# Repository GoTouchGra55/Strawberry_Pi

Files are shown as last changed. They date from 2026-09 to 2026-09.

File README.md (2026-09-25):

# 🍓 Strawberry Pi

A Raspberry Pi-4 form factor STM32 development board designed as a compact computing platform.

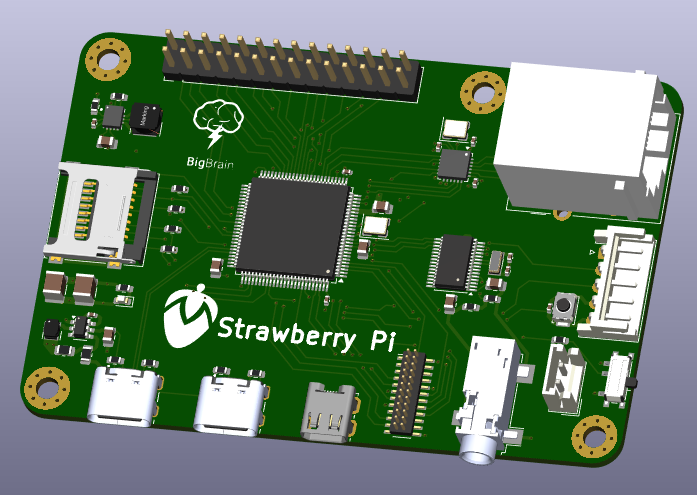
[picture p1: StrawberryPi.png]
Strawberry Pi


## Overview

Strawberry Pi is a custom 4-layer STM32-based development platform built around the **STM32H743** Cortex-M7 micro-controller.

The goal was to take the general concept of a small single-board computer and recreate it around a powerful micro-controller, integrating many useful interfaces and peripherals as possible into a compact Raspberry Pi 4 form factor.

The board is intended as a development and experimentation platform for hardware projects.

**SEE [SCHEMATICS](Strawberry_Pi-4.pdf)**

## Routing

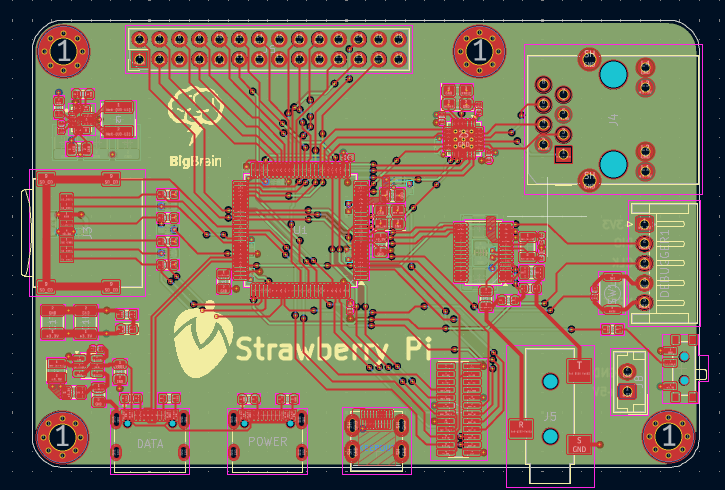
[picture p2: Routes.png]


## Features

### Core

- **STM32H743** Cortex-M7 MCU
- Up to **480 MHz** CPU clock
- MicroSD storage
- SWD debugging

### Connectivity

- **Ethernet**
- USB-C
- I2C
- SPI
- UART

### Multimedia

- Camera interface via **DCMI**
- Digital audio interface via **SAI**
- PCM1862 audio ADC
- 3.5 mm stereo audio input

### Power

The board provides dedicated:

- **5 V rail**
- **3.3 V rail**

## Rough BOM
| # | Item | Cost | Supplier |
|---|---|---:|---|
| 1 | PCB | $154.23 | JLCPCB |
| 2 | SMD Resistors | $8.35 | Daraz Nepal |
| 3 | SMD Capacitors | $7.98 | Daraz Nepal |
| | **Total** | **$170.56** | |

## Authors 👥

### Shaurya (Electronics)

Contact: [Email](shauryatamang.dev@gmail.com)

### Krish (CAD)

View: [Github](https://github.com/unknowngamer69/)

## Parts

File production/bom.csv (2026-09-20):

Designator | Footprint | Quantity | Value | LCSC Part #
 |  | 1
C1, C12, C16, C2, C23, C24, C26, C27, C28, C29, C3, C35, C4, C40, C5, C6, C8 | 0402 | 17 | 100nF
C10, C11, C30, C31 | 0402 | 4 | 18pF
C13, C14, C15 | 0805 | 3 | 2.2uF
C17, C18, C20, C21, C22, C33, C34 | 1210 | 7 | 22uF
C19, C25, C32, C36, C37 | 0805 | 5 | 10uF
C38, C39 | 0402 | 2 | 15pF
C7 | 0805 | 1 | 4.7uF
C9 | 0805 | 1 | 1uF
D1 | 0603 | 1 | GREEN
DEBUGGER1 | JST_EH_S5B-EH_1x05_P2.50mm_Horizontal | 1 | Conn_01x05_Pin
FB1 | 0603 | 1 | FerriteBead
J1 | SHOUHAN_TYPE-C_16PIN_2MD__073_ | 1 | POWER
J2 | SHOUHAN_TYPE-C_16PIN_2MD__073_ | 1 | DATA
J3 | microSD_HC_Wuerth | 1 | Micro_SD_Card_Det1
J4 | RJ45_Bel_SI-60062-F | 1 | RJ45_Bel_SI-60062-F
J5 | Jack_3.5mm_CUI_SJ-3523-SMT_Horizontal | 1 | AudioJack3
J6 | PinHeader_2x14_P2.54mm_Vertical | 1 | Conn_02x14_Counter_Clockwise
J7 | PinHeader_2x12_P1.00mm_Vertical_SMD | 1 | Conn_02x12_Odd_Even
J8 | JST_EH_B2B-EH-A_1x02_P2.50mm_Vertical | 1 | Conn_01x02_Pin
J9 | HDMI_Micro-D_Molex_46765-1xxx | 1 | HDMI_A
L1 | L_Wurth_WE-LQSH-2512 | 1 | 5.6uH
L2 | L_Wurth_WE-LQSH-4020 | 1 | 1.5uH
R1, R10, R12, R13, R14, R15, R16, R17, R9 | 0603 | 9 | 10K
R11 | 0603 | 1 | 33K
R18, R19 | 0603 | 2 | 2.2K
R2, R3, R7, R8 | 0603 | 4 | 5.1K
R4 | 0805 | 1 | 100K
R5 | 0805 | 1 | 22.1K
R6 | 0603 | 1 | 120R
SW1 | SW_Push_SPST_NO_Alps_SKRK | 1 | RESET
SW2 | SW_SPDT_PCM12 | 1 | BOOT
U1 | LQFP-100_14x14mm_P0.5mm | 1 | STM32H743VITx
U2 | SOT-23-6 | 1 | LMR51430
U3 | VREG_TPS63070RNMR | 1 | TPS63070RNMR
U4 | VQFN-24-1EP_4x4mm_P0.5mm_EP2.5x2.5mm_ThermalVias | 1 | LAN8742A
U5 | TSSOP-30_4.4x7.8mm_P0.5mm | 1 | PCM1862DBT
Y1, Y2 | Crystal_SMD_3225-4Pin_3.2x2.5mm | 2 | 25MHz
Y3 | Crystal_SMD_3215-2Pin_3.2x1.5mm | 1 | 8MHz

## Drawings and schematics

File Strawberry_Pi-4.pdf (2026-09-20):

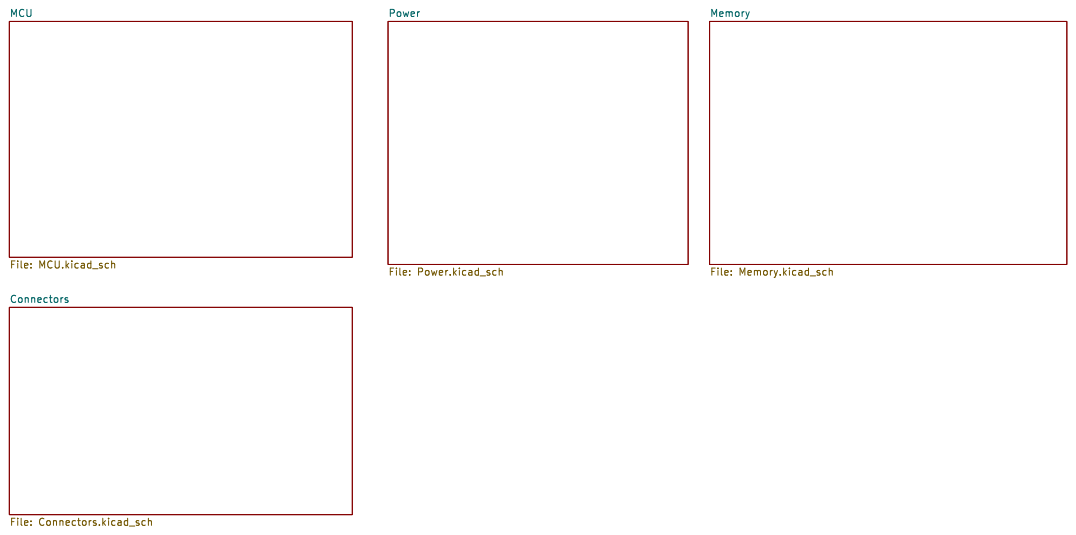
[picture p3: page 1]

Id: 1/5 Title: File: Strawberry_Pi-4.kicad_sch Sheet: /

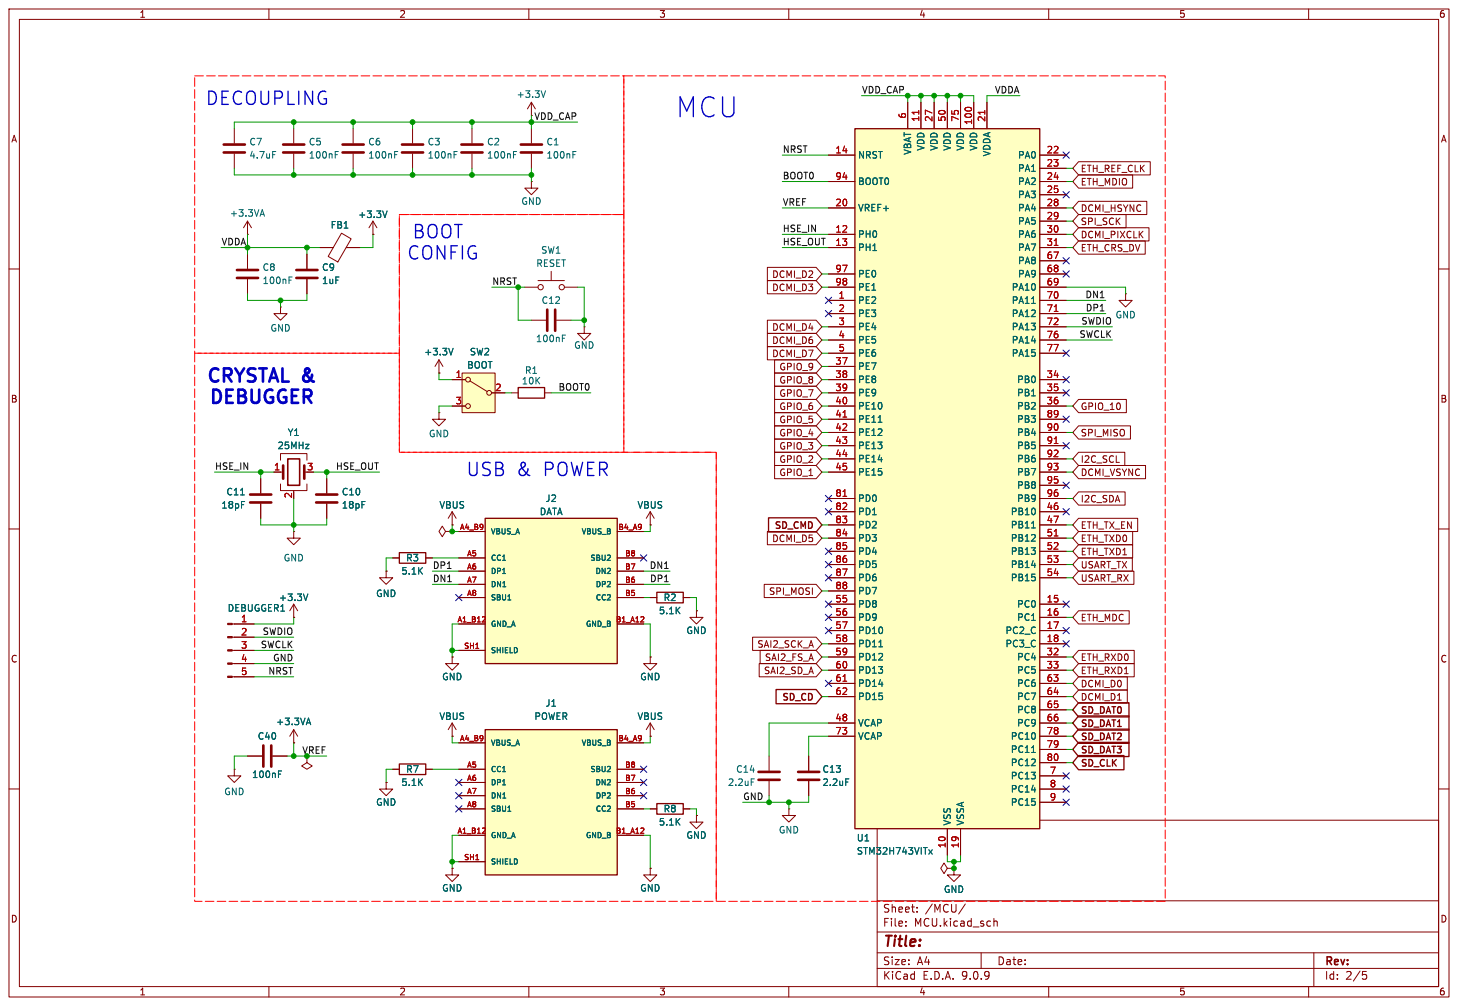
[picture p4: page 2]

Id: 2/5 Title: File: MCU.kicad_sch Sheet: /MCU/

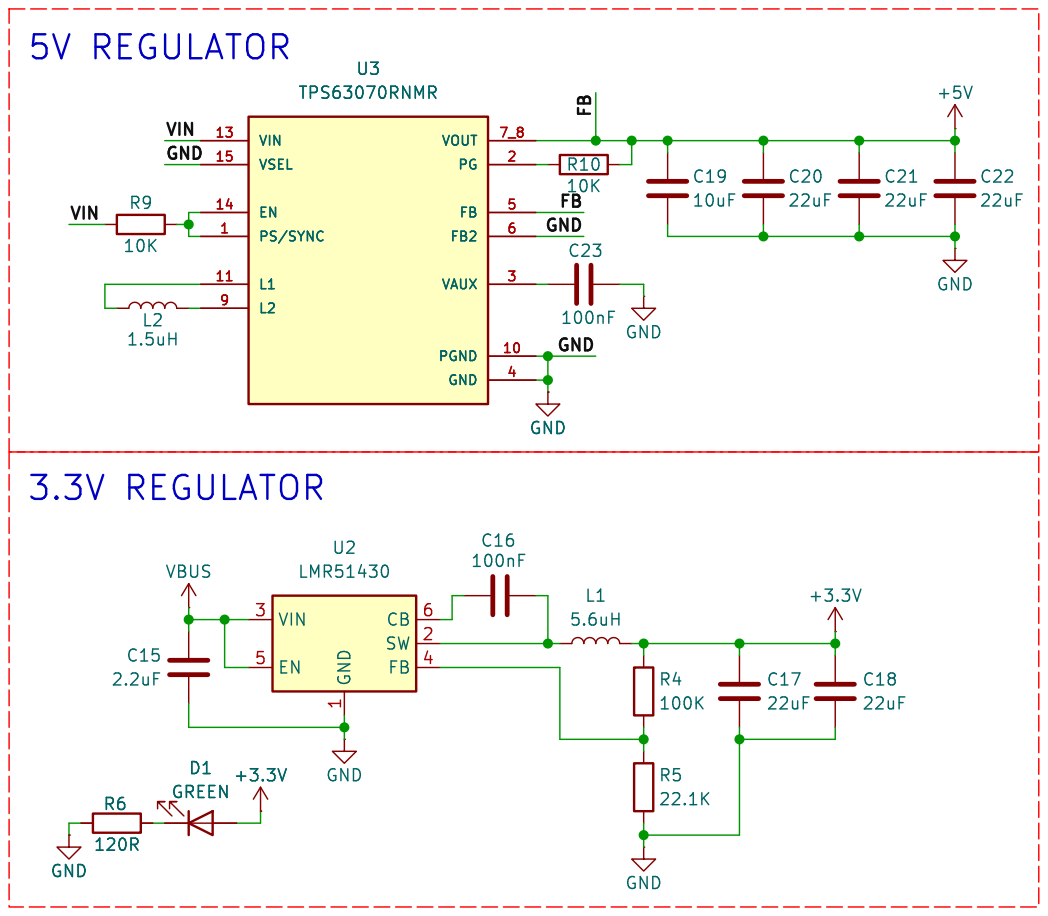
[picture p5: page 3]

Id: 3/5 Title: File: Power.kicad_sch Sheet: /Power/

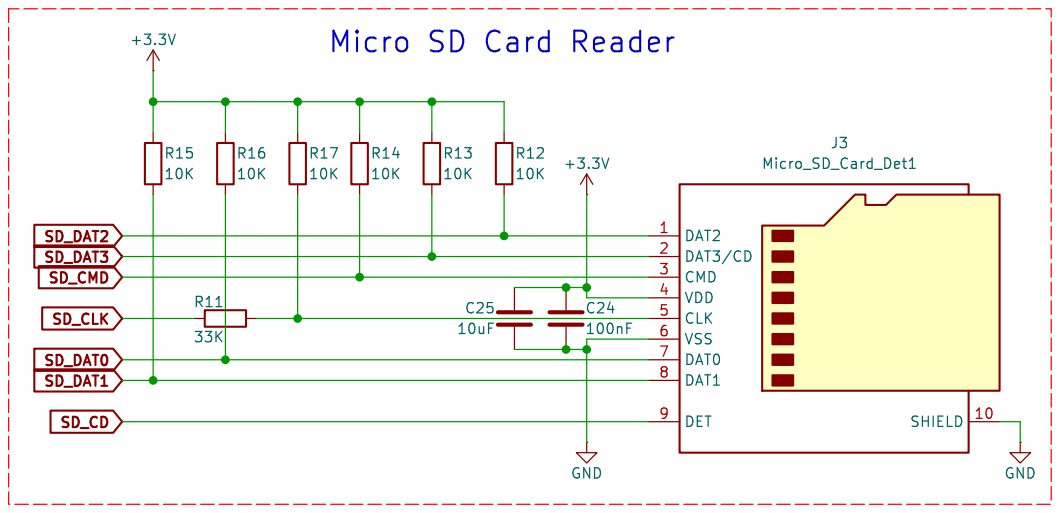
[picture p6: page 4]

Id: 4/5 Title: File: Memory.kicad_sch Sheet: /Memory/

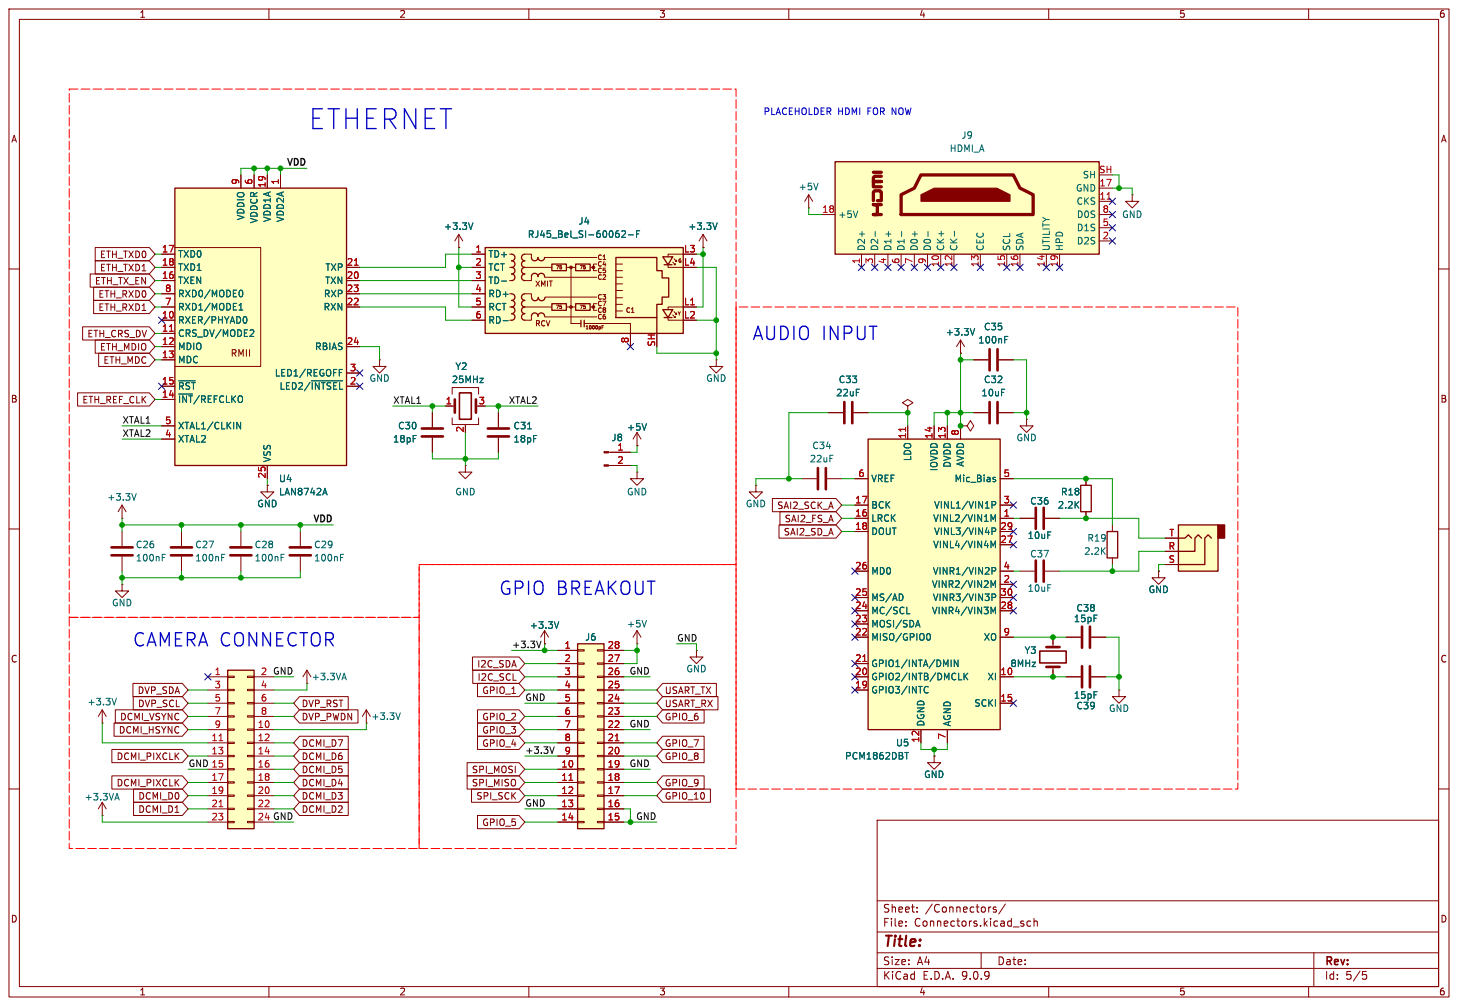
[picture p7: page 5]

PLACEHOLDER HDMI FOR NOW CAMERA CONNECTOR

7 D0- 9 CK+ 10 CK- 12 CEC 13 SCL 15 SDA 16 UTILITY 14 HPD 19 D2S 2 D1S 5 +5V 18 D0S 8 CKS 11 GND 17 SH SH
+3.3VGND

1 TXP 21 TXN 20 RXP 23 RXN 22 RBIAS 24

7 IOVDD 14 DGND 12 LDO 11 VREF 6 BCK 17

Id: 5/5 Title: File: Connectors.kicad_sch Sheet: /Connectors/

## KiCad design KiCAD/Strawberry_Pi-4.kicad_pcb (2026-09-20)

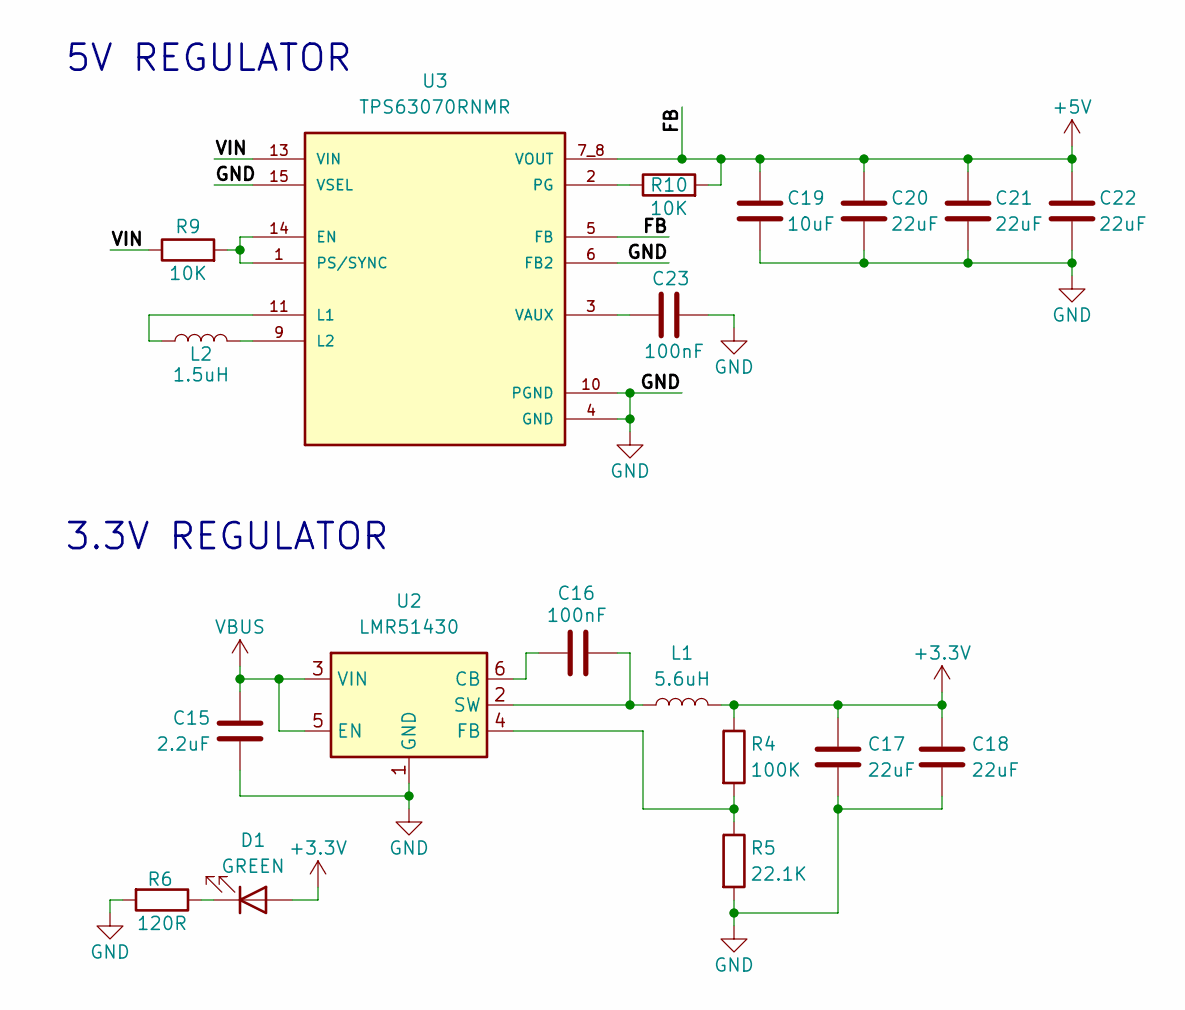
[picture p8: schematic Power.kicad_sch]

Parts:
C15: 2.2uF; C_0805_2012Metric
C16, C23: 100nF; C_0402_1005Metric
C17, C18, C20, C21, C22: 22uF; C_1210_3225Metric
C19: 10uF; C_0805_2012Metric
D1: GREEN; LED_0603_1608Metric
L1: 5.6uH; L_Wurth_WE-LQSH-2512
L2: 1.5uH; L_Wurth_WE-LQSH-4020
R4: 100K; R_0805_2012Metric
R5: 22.1K; R_0805_2012Metric
R6: 120R; R_0603_1608Metric
R9, R10: 10K; R_0603_1608Metric
U2: LMR51430; SOT-23-6
U3: TPS63070RNMR; VREG_TPS63070RNMR; PARTREV B

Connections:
+3.3V: C17.1, C18.1, D1.2 (A), L1.2, R4.1; also elsewhere on the board
+5V: C19.1, C20.1, C21.1, C22.1, R10.2, U3.5 (FB), U3.7_8 (VOUT); also elsewhere on the board
/Power/VIN: R9.1, U3.13 (VIN)
GND: C15.2, C17.2, C18.2, C19.2, C20.2, C21.2, C22.2, C23.2, R5.2, R6.2, U2.1 (GND), U3.4 (GND), U3.6 (FB2), U3.10 (PGND), U3.15 (VSEL); also elsewhere on the board
unnamed: D1.1 (K), R6.1
unnamed: C16.2, U2.6 (CB)
unnamed: R4.2, R5.1, U2.4 (FB)
unnamed: C16.1, L1.1, U2.2 (SW)
unnamed: R9.2, U3.1 (PS/SYNC), U3.14 (EN)
unnamed: L2.1, U3.11 (L1)
unnamed: L2.2, U3.9 (L2)
unnamed: R10.1, U3.2 (PG)
unnamed: C23.1, U3.3 (VAUX)
VBUS: C15.1, U2.3 (VIN), U2.5 (EN); also elsewhere on the board

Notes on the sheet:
5V REGULATOR
3.3V REGULATOR

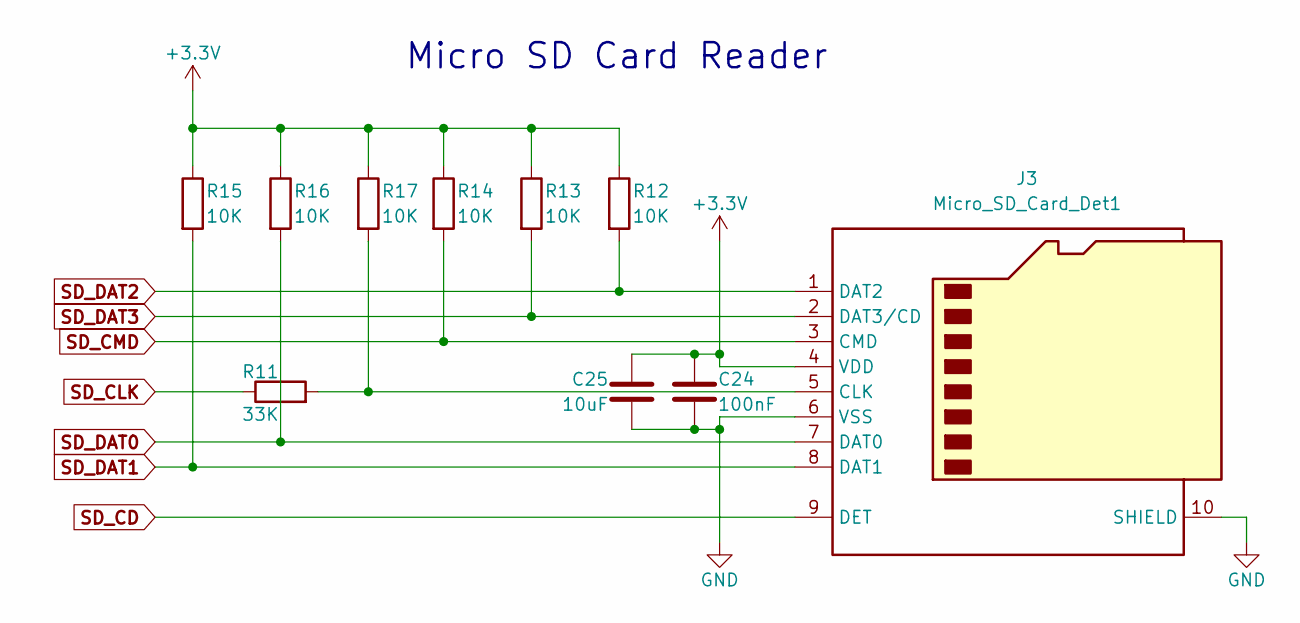
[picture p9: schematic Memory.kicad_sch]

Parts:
C24: 100nF; C_0402_1005Metric
C25: 10uF; C_0805_2012Metric
J3: Micro_SD_Card_Det1; microSD_HC_Wuerth
R11: 33K; R_0603_1608Metric
R12, R13, R14, R15, R16, R17: 10K; R_0603_1608Metric

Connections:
+3.3V: C24.1, C25.1, J3.4 (VDD), R12.1, R13.1, R14.1, R15.1, R16.1, R17.1; also elsewhere on the board
GND: C24.2, C25.2, J3.6 (VSS), J3.10 (SHIELD); also elsewhere on the board
unnamed: J3.5 (CLK), R11.2, R17.2
SD_CD: J3.9 (DET); also elsewhere on the board
SD_CLK: R11.1; also elsewhere on the board
SD_CMD: J3.3 (CMD), R14.2; also elsewhere on the board
SD_DAT0: J3.7 (DAT0), R16.2; also elsewhere on the board
SD_DAT1: J3.8 (DAT1), R15.2; also elsewhere on the board
SD_DAT2: J3.1 (DAT2), R12.2; also elsewhere on the board
SD_DAT3: J3.2 (DAT3/CD), R13.2; also elsewhere on the board

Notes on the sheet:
Micro SD Card Reader

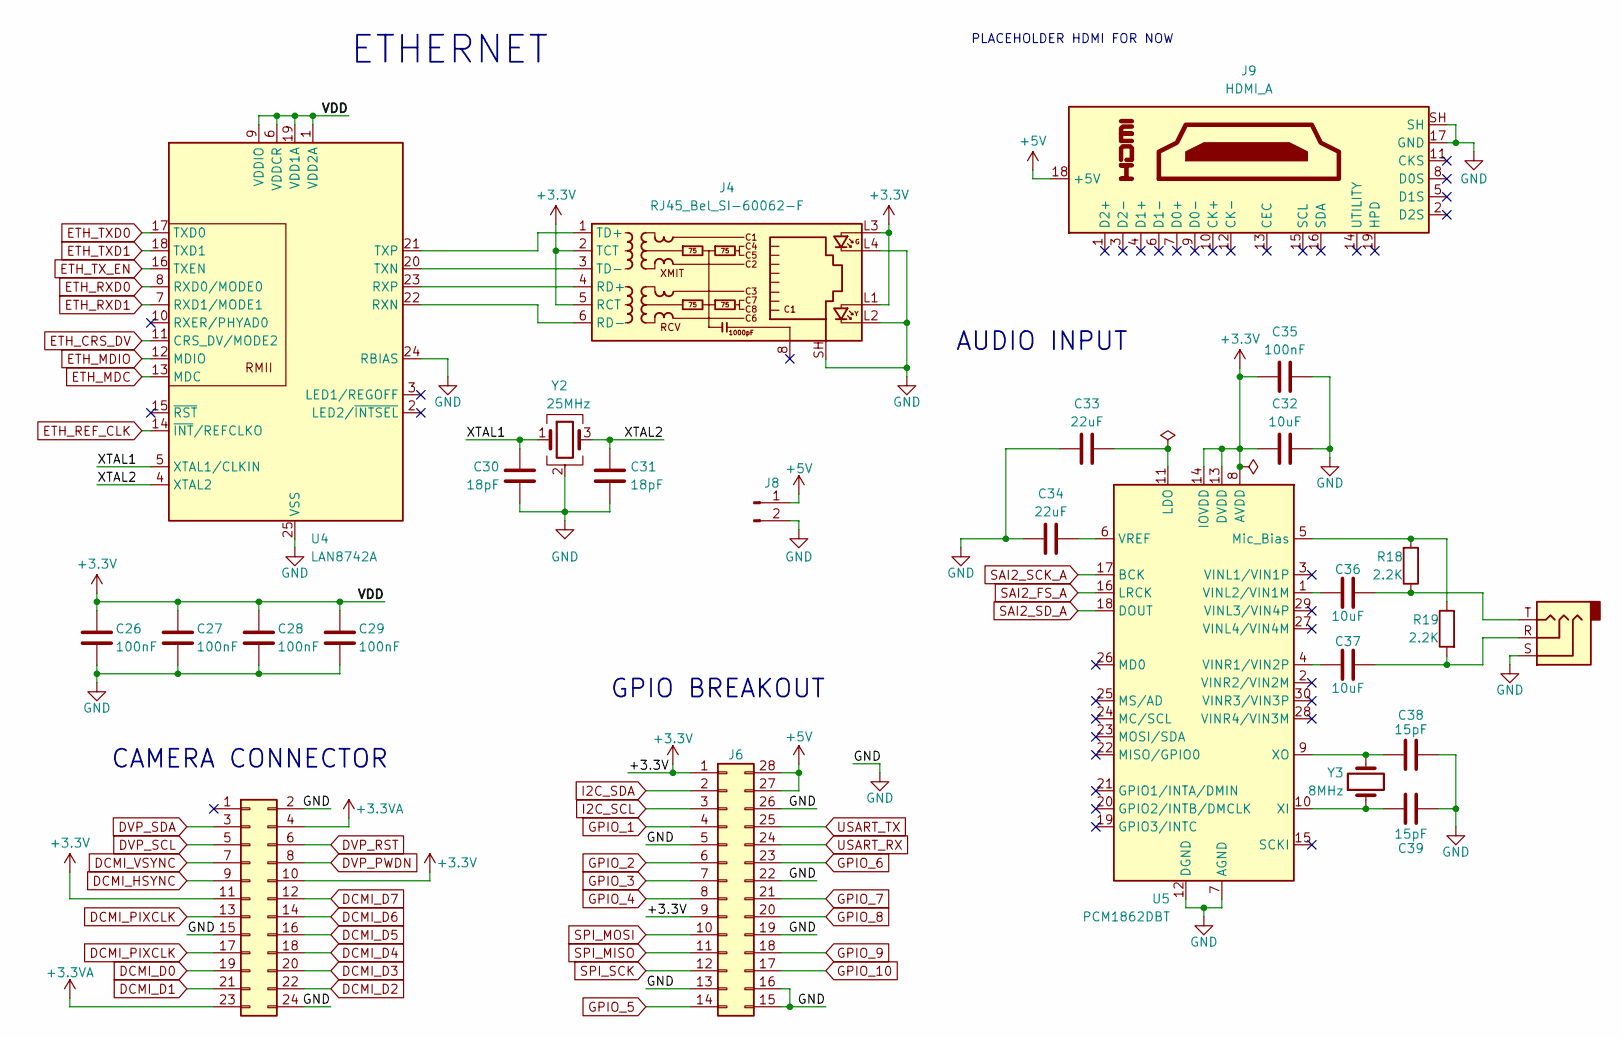
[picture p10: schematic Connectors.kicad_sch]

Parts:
C26, C27, C28, C29, C35: 100nF; C_0402_1005Metric
C30, C31: 18pF; C_0402_1005Metric
C32, C36, C37: 10uF; C_0805_2012Metric
C33, C34: 22uF; C_1210_3225Metric
C38, C39: 15pF; C_0402_1005Metric
J4: RJ45_Bel_SI-60062-F
J5: AudioJack3; Jack_3.5mm_CUI_SJ-3523-SMT_Horizontal
J6: Conn_02x14_Counter_Clockwise; PinHeader_2x14_P2.54mm_Vertical
J7: Conn_02x12_Odd_Even; PinHeader_2x12_P1.00mm_Vertical_SMD
J8: Conn_01x02_Pin; JST_EH_B2B-EH-A_1x02_P2.50mm_Vertical
J9: HDMI_A; HDMI_Micro-D_Molex_46765-1xxx
R18, R19: 2.2K; R_0603_1608Metric
U4: LAN8742A; VQFN-24-1EP_4x4mm_P0.5mm_EP2.5x2.5mm_ThermalVias
U5: PCM1862DBT; TSSOP-30_4.4x7.8mm_P0.5mm
Y2: 25MHz; Crystal_SMD_3225-4Pin_3.2x2.5mm
Y3: 8MHz; Crystal_SMD_3215-2Pin_3.2x1.5mm

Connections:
+3.3V: C26.1, C27.1, C28.1, C29.1, C32.2, C35.2, J4.2 (TCT), J4.5 (RCT), J4.L1, J4.L3, J6.1, J6.9, J7.10, J7.11, U4.1 (VDD2A), U4.6 (VDDCR), U4.9 (VDDIO), U4.19 (VDD1A), U5.8 (AVDD), U5.13 (DVDD), U5.14 (IOVDD); also elsewhere on the board
+3.3VA: J7.4, J7.23; also elsewhere on the board
+5V: J6.27, J6.28, J8.1, J9.18 (+5V); also elsewhere on the board
/Connectors/XTAL1: C30.1, U4.5 (XTAL1/CLKIN), Y2.1
/Connectors/XTAL2: C31.1, U4.4 (XTAL2), Y2.3
DCMI_D0: J7.19; also elsewhere on the board
DCMI_D1: J7.21; also elsewhere on the board
DCMI_D2: J7.22; also elsewhere on the board
DCMI_D3: J7.20; also elsewhere on the board
DCMI_D4: J7.18; also elsewhere on the board
DCMI_D5: J7.16; also elsewhere on the board
DCMI_D6: J7.14; also elsewhere on the board
DCMI_D7: J7.12; also elsewhere on the board
DCMI_HSYNC: J7.9; also elsewhere on the board
DCMI_PIXCLK: J7.13, J7.17; also elsewhere on the board
DCMI_VSYNC: J7.7; also elsewhere on the board
DVP_PWDN: J7.8
DVP_RST: J7.6
DVP_SCL: J7.5
DVP_SDA: J7.3
ETH_CRS_DV: U4.11 (CRS_DV/MODE2); also elsewhere on the board
ETH_MDC: U4.13 (MDC); also elsewhere on the board
ETH_MDIO: U4.12 (MDIO); also elsewhere on the board
ETH_REF_CLK: U4.14 (~INT/REFCLKO); also elsewhere on the board
ETH_RXD0: U4.8 (RXD0/MODE0); also elsewhere on the board
ETH_RXD1: U4.7 (RXD1/MODE1); also elsewhere on the board
ETH_TXD0: U4.17 (TXD0); also elsewhere on the board
ETH_TXD1: U4.18 (TXD1); also elsewhere on the board
ETH_TX_EN: U4.16 (TXEN); also elsewhere on the board
GND: C26.2, C27.2, C28.2, C29.2, C30.2, C31.2, C32.1, C33.2, C34.2, C35.1, C38.1, C39.1, J4.L2, J4.L4, J4.SH, J5.S, J6.5, J6.13, J6.15, J6.16, J6.19, J6.22, J6.26, J7.2, J7.15, J7.24, J8.2, J9.17 (GND), J9.SH, U4.24 (RBIAS), U4.25 (VSS), U5.7 (AGND), U5.12 (DGND), Y2.2 (G), Y2.4 (G); also elsewhere on the board
GPIO_1: J6.4; also elsewhere on the board
GPIO_2: J6.6; also elsewhere on the board
GPIO_3: J6.7; also elsewhere on the board
GPIO_4: J6.8; also elsewhere on the board
GPIO_5: J6.14; also elsewhere on the board
GPIO_6: J6.23; also elsewhere on the board
GPIO_7: J6.21; also elsewhere on the board
GPIO_8: J6.20; also elsewhere on the board
GPIO_9: J6.18; also elsewhere on the board
GPIO_10: J6.17; also elsewhere on the board
I2C_SCL: J6.3; also elsewhere on the board
I2C_SDA: J6.2; also elsewhere on the board
unnamed: C36.1, J5.T, R18.1
unnamed: C37.1, J5.R, R19.2
unnamed: J4.4 (RD+), U4.23 (RXP)
unnamed: J4.6 (RD-), U4.22 (RXN)
unnamed: J4.1 (TD+), U4.21 (TXP)
unnamed: J4.3 (TD-), U4.20 (TXN)
unnamed: C33.1, U5.11 (LDO)
unnamed: R18.2, R19.1, U5.5 (Mic_Bias)
unnamed: C36.2, U5.1 (VINL2/VIN1M)
unnamed: C37.2, U5.4 (VINR1/VIN2P)
unnamed: C34.1, U5.6 (VREF)
unnamed: C39.2, U5.10 (XI), Y3.1
unnamed: C38.2, U5.9 (XO), Y3.2
SAI2_FS_A: U5.16 (LRCK); also elsewhere on the board
SAI2_SCK_A: U5.17 (BCK); also elsewhere on the board
SAI2_SD_A: U5.18 (DOUT); also elsewhere on the board
SPI_MISO: J6.11; also elsewhere on the board
SPI_MOSI: J6.10; also elsewhere on the board
SPI_SCK: J6.12; also elsewhere on the board
USART_RX: J6.24; also elsewhere on the board
USART_TX: J6.25; also elsewhere on the board

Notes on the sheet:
GPIO BREAKOUT
PLACEHOLDER HDMI FOR NOW
ETHERNET
CAMERA CONNECTOR
AUDIO INPUT

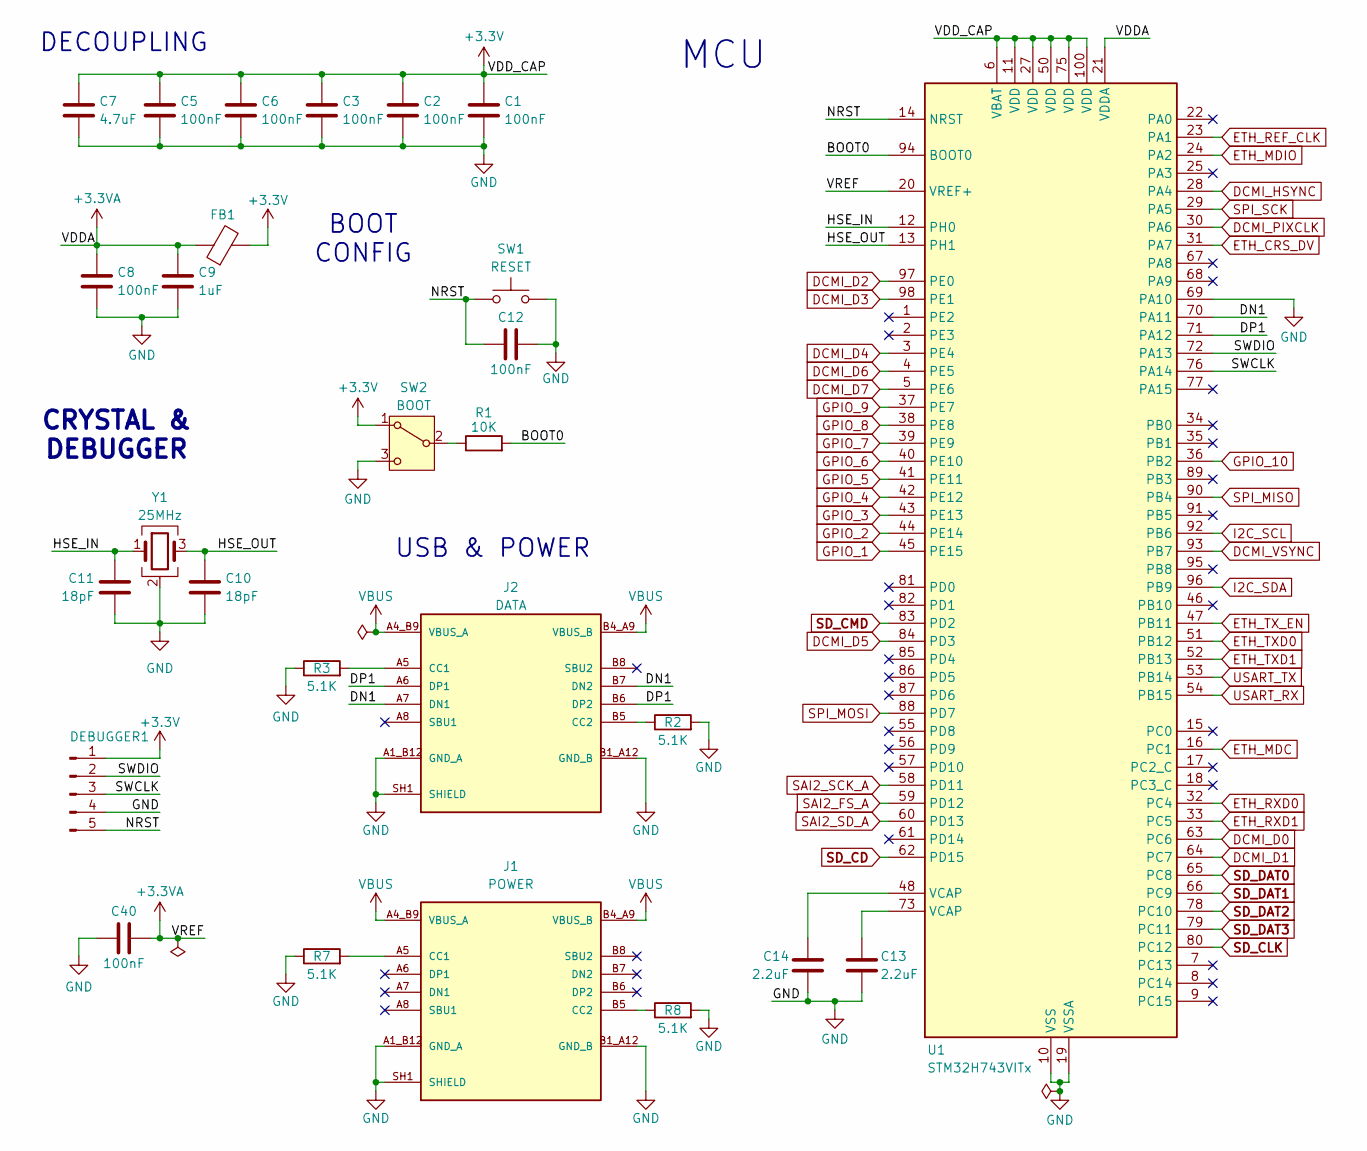
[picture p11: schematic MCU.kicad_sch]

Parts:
C1, C2, C3, C5, C6, C8, C12, C40: 100nF; C_0402_1005Metric
C7: 4.7uF; C_0805_2012Metric
C9: 1uF; C_0805_2012Metric
C10, C11: 18pF; C_0402_1005Metric
C13, C14: 2.2uF; C_0805_2012Metric
DEBUGGER1: Conn_01x05_Pin; JST_EH_S5B-EH_1x05_P2.50mm_Horizontal
FB1: FerriteBead; D_0603_1608Metric
J1: POWER; SHOUHAN_TYPE-C_16PIN_2MD__073_; PARTREV A
J2: DATA; SHOUHAN_TYPE-C_16PIN_2MD__073_; PARTREV A
R1: 10K; R_0603_1608Metric
R2, R3, R7, R8: 5.1K; R_0603_1608Metric
SW1: RESET; SW_Push_SPST_NO_Alps_SKRK
SW2: BOOT; SW_SPDT_PCM12
U1: STM32H743VITx; LQFP-100_14x14mm_P0.5mm
Y1: 25MHz; Crystal_SMD_3225-4Pin_3.2x2.5mm

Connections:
+3.3V: C1.1, C2.1, C3.1, C5.1, C6.1, C7.1, DEBUGGER1.1, FB1.2, SW2.1 (A), U1.6 (VBAT), U1.11 (VDD), U1.27 (VDD), U1.50 (VDD), U1.75 (VDD), U1.100 (VDD); also elsewhere on the board
+3.3VA: C8.1, C9.1, C40.1, FB1.1, U1.20 (VREF+), U1.21 (VDDA); also elsewhere on the board
/MCU/BOOT0: R1.2, U1.94 (BOOT0)
/MCU/DN1: J2.A7 (DN1), J2.B7 (DN2), U1.70 (PA11)
/MCU/DP1: J2.A6 (DP1), J2.B6 (DP2), U1.71 (PA12)
/MCU/HSE_IN: C11.1, U1.12 (PH0), Y1.1
/MCU/HSE_OUT: C10.1, U1.13 (PH1), Y1.3
/MCU/NRST: C12.2, DEBUGGER1.5, SW1.2, U1.14 (NRST)
/MCU/SWCLK: DEBUGGER1.3, U1.76 (PA14)
/MCU/SWDIO: DEBUGGER1.2, U1.72 (PA13)
DCMI_D0: U1.63 (PC6); also elsewhere on the board
DCMI_D1: U1.64 (PC7); also elsewhere on the board
DCMI_D2: U1.97 (PE0); also elsewhere on the board
DCMI_D3: U1.98 (PE1); also elsewhere on the board
DCMI_D4: U1.3 (PE4); also elsewhere on the board
DCMI_D5: U1.84 (PD3); also elsewhere on the board
DCMI_D6: U1.4 (PE5); also elsewhere on the board
DCMI_D7: U1.5 (PE6); also elsewhere on the board
DCMI_HSYNC: U1.28 (PA4); also elsewhere on the board
DCMI_PIXCLK: U1.30 (PA6); also elsewhere on the board
DCMI_VSYNC: U1.93 (PB7); also elsewhere on the board
ETH_CRS_DV: U1.31 (PA7); also elsewhere on the board
ETH_MDC: U1.16 (PC1); also elsewhere on the board
ETH_MDIO: U1.24 (PA2); also elsewhere on the board
ETH_REF_CLK: U1.23 (PA1); also elsewhere on the board
ETH_RXD0: U1.32 (PC4); also elsewhere on the board
ETH_RXD1: U1.33 (PC5); also elsewhere on the board
ETH_TXD0: U1.51 (PB12); also elsewhere on the board
ETH_TXD1: U1.52 (PB13); also elsewhere on the board
ETH_TX_EN: U1.47 (PB11); also elsewhere on the board
GND: C1.2, C2.2, C3.2, C5.2, C6.2, C7.2, C8.2, C9.2, C10.2, C11.2, C12.1, C13.2, C14.2, C40.2, DEBUGGER1.4, J1.A1_B12 (GND_A), J1.B1_A12 (GND_B), J1.SH1 (SHIELD), J1.SH2 (SHIELD), J1.SH3 (SHIELD), J1.SH4 (SHIELD), J2.A1_B12 (GND_A), J2.B1_A12 (GND_B), J2.SH1 (SHIELD), J2.SH2 (SHIELD), J2.SH3 (SHIELD), J2.SH4 (SHIELD), R2.2, R3.1, R7.1, R8.2, SW1.1, SW2.3 (C), U1.10 (VSS), U1.19 (VSSA), U1.26 (VSS), U1.49 (VSS), U1.69 (PA10), U1.74 (VSS), U1.99 (VSS), Y1.2 (G), Y1.4 (G); also elsewhere on the board
GPIO_1: U1.45 (PE15); also elsewhere on the board
GPIO_2: U1.44 (PE14); also elsewhere on the board
GPIO_3: U1.43 (PE13); also elsewhere on the board
GPIO_4: U1.42 (PE12); also elsewhere on the board
GPIO_5: U1.41 (PE11); also elsewhere on the board
GPIO_6: U1.40 (PE10); also elsewhere on the board
GPIO_7: U1.39 (PE9); also elsewhere on the board
GPIO_8: U1.38 (PE8); also elsewhere on the board
GPIO_9: U1.37 (PE7); also elsewhere on the board
GPIO_10: U1.36 (PB2); also elsewhere on the board
I2C_SCL: U1.92 (PB6); also elsewhere on the board
I2C_SDA: U1.96 (PB9); also elsewhere on the board
unnamed: C13.1, U1.73 (VCAP)
unnamed: C14.1, U1.48 (VCAP)
unnamed: J1.A5 (CC1), R7.2
unnamed: J1.B5 (CC2), R8.1
unnamed: J2.A5 (CC1), R3.2
unnamed: J2.B5 (CC2), R2.1
unnamed: R1.1, SW2.2 (B)
SAI2_FS_A: U1.59 (PD12); also elsewhere on the board
SAI2_SCK_A: U1.58 (PD11); also elsewhere on the board
SAI2_SD_A: U1.60 (PD13); also elsewhere on the board
SD_CD: U1.62 (PD15); also elsewhere on the board
SD_CLK: U1.80 (PC12); also elsewhere on the board
SD_CMD: U1.83 (PD2); also elsewhere on the board
SD_DAT0: U1.65 (PC8); also elsewhere on the board
SD_DAT1: U1.66 (PC9); also elsewhere on the board
SD_DAT2: U1.78 (PC10); also elsewhere on the board
SD_DAT3: U1.79 (PC11); also elsewhere on the board
SPI_MISO: U1.90 (PB4); also elsewhere on the board
SPI_MOSI: U1.88 (PD7); also elsewhere on the board
SPI_SCK: U1.29 (PA5); also elsewhere on the board
USART_RX: U1.54 (PB15); also elsewhere on the board
USART_TX: U1.53 (PB14); also elsewhere on the board
VBUS: J1.A4_B9 (VBUS_A), J1.B4_A9 (VBUS_B), J2.A4_B9 (VBUS_A), J2.B4_A9 (VBUS_B); also elsewhere on the board

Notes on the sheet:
DECOUPLING
CRYSTAL & DEBUGGER
USB & POWER
BOOT CONFIG
MCU

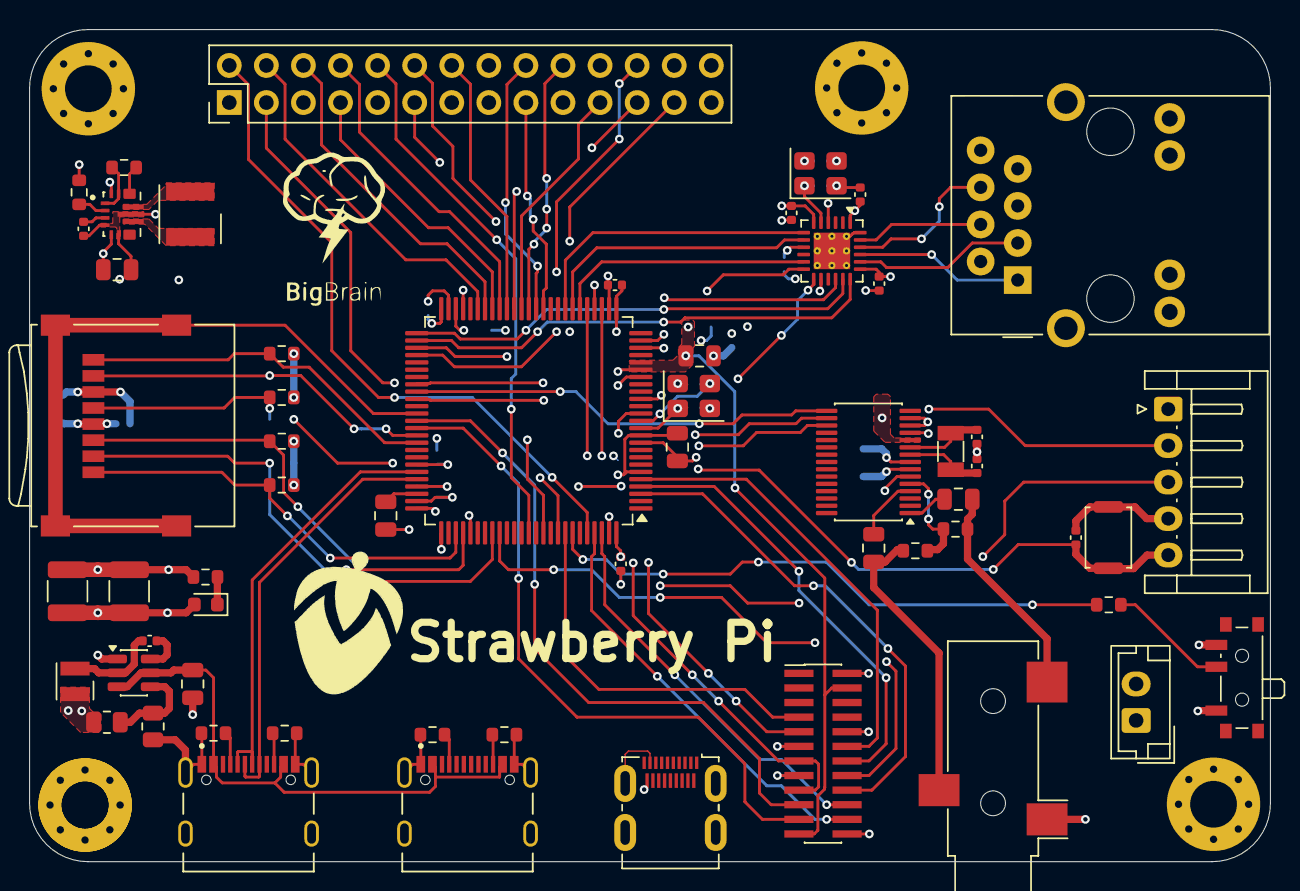
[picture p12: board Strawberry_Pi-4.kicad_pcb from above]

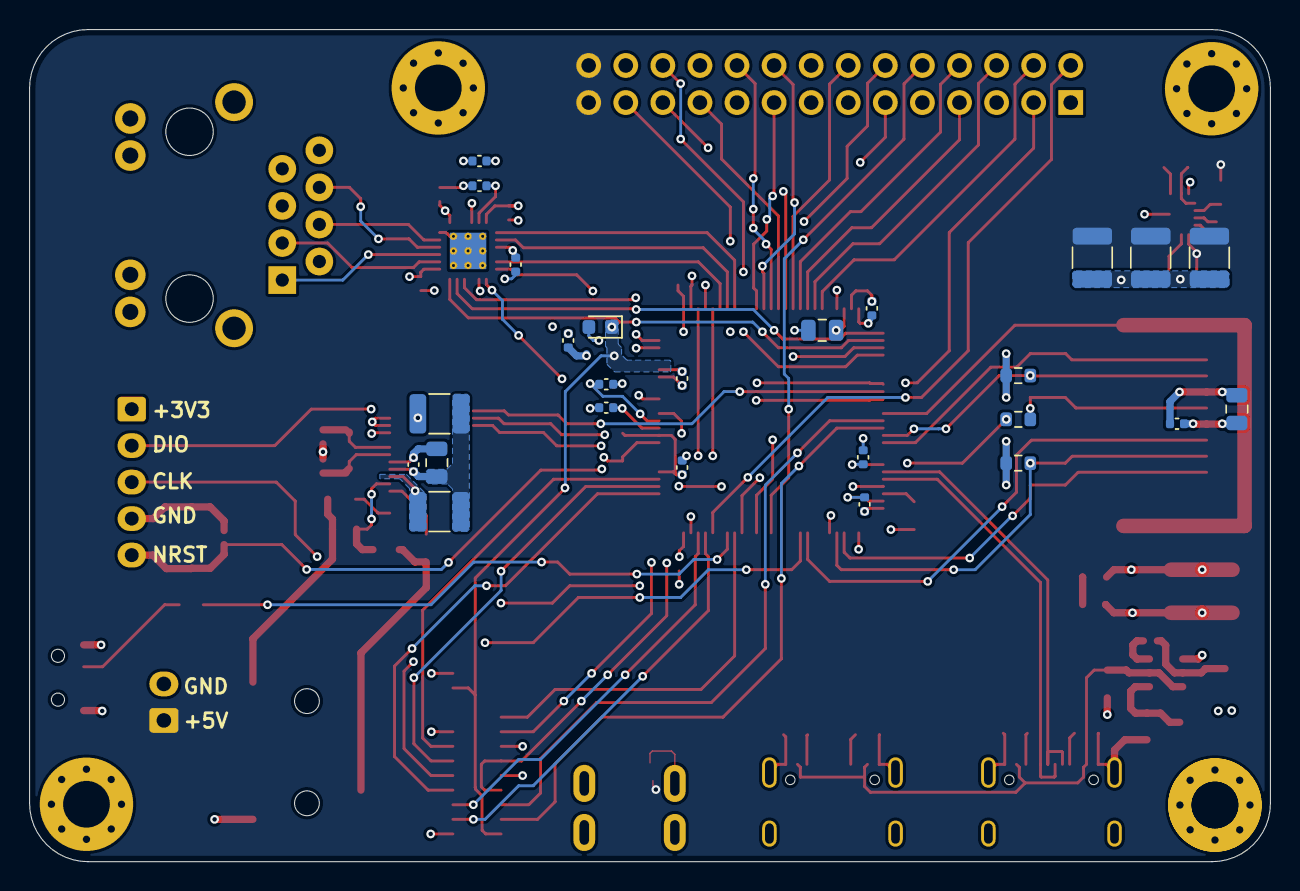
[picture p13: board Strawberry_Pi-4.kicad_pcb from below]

Board: 4 copper layers, 85.0 x 57.0 mm, 83 parts (25 on the bottom side), 93 nets.

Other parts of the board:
C4: 100nF; C_0402_1005Metric

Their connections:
+3.3V: C4.1; also elsewhere on the board
GND: C4.2; also elsewhere on the board

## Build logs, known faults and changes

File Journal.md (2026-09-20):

# Strawberry_Pi

## Day 1

I spent the entire day configuring the wiring up the strawberry pi board. Originally I wanted to use the stm32h757ZIYxx, but it was just way too complex due to the dual mcu architecture. I spent a whole lot of time on cubemx configuring that but it eventually went to waste. But I then went up with my trusty stm32h743vitx. Sure I had to remove some features like display but what it lost in functionality, it gained in it's convenience.

https://lapse.hackclub.com/timelapse/_1ylYZns9QVY

Then, I just read datasheets for the stm32 (On a separate device. So you won't see me changing windows very often.) and wired it up. Then the power components and finally the memory section.

https://lapse.hackclub.com/timelapse/YPAaonDyC28P

Finally, I wired up the ethernet and the camera connectors. I was pretty confused at first regarding the etherned wiring as the references showed differential paris while cubemx had configured something else. But after a quick google search, I came to know that it was because of the RMII setting I had set up in cubemx. I just needed a small chip and a suitable ethernet connector.

https://lapse.hackclub.com/timelapse/z4tXTK4zzKuB

## Day 2

Today was spent on finishing schematics!!!
I wired up the fan and breakout connectiors for SPI, I2C, UART, and 10 GPIO ports. I also wired the audio input connector and fixed any broken/error-prone connections. We had originally planned on a raspberry pi 4 form-factor board but due to the lack of USB-A ports, it's not feasible at the moment. So, I think we'll go with a raspberry pi zero form-factor but with ethernet capabilities like board.

https://lapse.hackclub.com/timelapse/AY0L5Gldac55

## Day 3

THE BOARD IS COMPLETE!!! After 3 days of hard work, I finally finished the rpi-4 form factor Strawberry Pi. I have a total of 5 lapse times today. The first one is only 5 mins long bc my laptop decided to die in the middle of work. Here, I was p
lanning out the board.

https://lapse.hackclub.com/timelapse/ifrvSFvBeYo9

Then, I started work on finalizing sections and also editing any footprint/3d model errors. There were a lot of those for some reason but I fixed it. I planned out the component placements too. It was scary at first because of all the ratsnest lines going all over the board but little by little, I tidied it up to my abilities and it started to take shape.

https://lapse.hackclub.com/timelapse/IUfBVHrY7pCA
https://lapse.hackclub.com/timelapse/HjVgqjR3aEW2

Finally, I routed the components and added aesthetics to fill in the blank spaces and to make the board a little less empty. Lemme tell you, aesthetics add SOO much personality to a pcb project. Even the pcb routes make the board look pretty. I may not have the prettiest board, but some sections of this pcb are beautiful to me. Thus, I finished the board!

https://lapse.hackclub.com/timelapse/Y_POSmpzjU_k
https://lapse.hackclub.com/timelapse/AnoPyOCp-v4V

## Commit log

2026-09-19 Finish Schematics
2026-09-20 Add project files
    [Connectors.kicad_sch, Decoupling.kicad_sch, MCU.kicad_sch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]
2026-09-25 Add rough BOM section to README
    Added a rough bill of materials (BOM) with costs for components.
2026-09-25 Revise BOM section to use a table format
    Updated BOM format to a table for better readability.
